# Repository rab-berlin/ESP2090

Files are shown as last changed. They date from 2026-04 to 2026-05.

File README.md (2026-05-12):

# Bring deinen Busch Microtronic 2090 ins 21. Jahrhundert!

ESP2090-Studio

Das ESP2090-Studio verbindet den klassischen Lerncomputer Busch Microtronic 2090 mit einem modernen ESP32. ESP2090 erweitert den Microtronic um flexible, programmierbare Peripherie.

Der Grundgedanke ist einfach: Der Microtronic bleibt das originale 4-Bit-System – das ESP2090-Studio sorgt dafür, dass er plötzlich Dinge kann, die er ursprünglich nie konnte, ohne ihn selbst zu ersetzen. Wir verbinden dafür die Ein- und Ausgänge des Microtronic mit einem [ESP32](https://de.wikipedia.org/wiki/ESP32), auf dem [MicroPython](https://micropython.org) läuft. So können benutzerdefinierte Python-Programme über festgelegte Funktionen und Protokolle mit dem Microtronic interagieren. 

Vom einfachen Blinklicht über anpassbaren Zufallszahlengenerator, 2095-Tape-Emulator, Tongenerator, beliebige Sensoren, Internet-Anbindung bis hin zu einem 8x8-Matrix-LED-"Bildschirm" für den Microtronic - über die Weboberfläche des ESP2090-Studios lässt sich alles konfigurieren und steuern. 

Webscreen

## Materialliste (BOM)

| Menge | Artikel | Preis (04/26) | Bemerkung |
| ---: | :--- | ---: | :--- |
| 1 | ESP32-C3 SuperMini | 1,70 | |
| 1 | SN74HCT244 8-fach Treiber | 2,60 | (10 St.) |
| 1 | CD4071 4-fach Oder-Gatter | 1,70 | (10 St.) |
| 2 | 4ch-2way-Levelshifter | 1,70 | (10 St., richtige Bauform beachten) |
| 1 | Buzzer, passiv | 1,50 | (10 St.) |
| 4 | Widerstand 470 Ohm | 2,00 | (Sortiment Widerstände 300 St.) |
| 4 | Widerstand 10k Ohm | - | (s.o.) |
| 1 | Widerstand 220 Ohm | - | (s.o.) |
| 1 | Widerstand 100 Ohm | - | (s.o.) |
| 2 | Kondensator 100 nF | 2,30 | (Sortiment Kondensatoren 300 St.) |
| 1 | Pfostenleiste 2,54 mm | 1,80 | (Sortiment male + female 20 St., benötigt male: 1 x 5, 1 x 3) |
| 1 | Buchsenleiste 2,54 mm | - | (s.o., benötigt female: 2 x 8 für ESP32) |
| 1 | IC-Sockel 14-polig | 2,20 | (Sortiment 66 St., für CD4071)
| 1 | IC-Sockel 20-polig | - | (s.o., für 74HCT244) |
| 18 | Metallösen 2,5 mm Innendurchmesser | 1,80 | (Sortiment 100 St., Stichwort: rivet, eyelet) |
| 1 | [Platine (PCB)](https://github.com/rab-berlin/ESP2090/tree/main/gerbers) | 9,00 | (5 St. aus Fernost - oder von mir, falls noch da) |
| 1 | WS2812B-LED-Matrix 8x8 | 1,80 | |
| 1 | Netzteil 5V 3A USB-C | 3,30 | |

Die Preise sind von AliExpress. Wer das alles frisch ordert, kommt ohne Platine für etwa 20 Euro weg - und hat danach noch viele Ersatzteile übrig. Ich bin aber sicher, dass du das meiste sowieso schon vorrätig hast. Lediglich den ESP, die Metallösen, die Platine und wahrscheinlich die LED-Matrix musst du wohl bestellen.

Du kannst natürlich auch ohne IC-Sockel und Buchsenleisten alles direkt auf die Platine löten. Ich persönlich hab´s aber lieber flexibel - versuch mal, einen falsch eingelöteten oder nicht funktionierenden IC wieder auszulöten...

Wer es richtig schön will, druckt sich noch einen passenden Busch-Bauteilträger dazu aus. ~~Daran arbeite ich noch...~~ [SCAD-](https://github.com/rab-berlin/ESP2090/blob/main/3d/ESP2090_mit_Zapfen.scad) und STL-Datei. Zur Befestigung der Platine am Träger brauchst du vier winzige Schrauben M2 und passende Muttern.

## Warum nur, warum?

Für den Test von neu geschriebenen oder geänderten Programmen habe ich zunächst den prima [Emulator von Michael Wessel](https://github.com/lambdamikel/Busch-2090) verwendet. Am PC entwickelt, auf SD-Karte geschrieben, in den Emulator umgestöpselt und übertragen... Haltnextnullnullrun...

Als ich dann auch mal auf dem "echten" Microtronic testen wollte, stieß ich - unter anderem - auf den Unterschied zwischen zufälligem und nicht so zufälligem Zufall. Also ergaben sich neue Notwendigkeiten:

- mehr auf dem originalen Busch Microtronic 2090 testen
- besondere Peripherie für meine Programme anschließen

Daher habe ich dann einen Raspberry Pi Zero W eingesetzt. Ein Python-Skript und ein paar Kabel mit Levelshifter übernahmen die Funktion des 2095-Kassetteninterfaces, und so konnte ich meine Ideen relativ schnell und unkompliziert über WLAN auf den Pi und von dort auf den Original-2090 bringen.

Für einige dieser neuen Programme wiederum benötigte ich manchmal auch Peripherie am Microtronic, die ich nicht immer mit Busch-Baukästen umsetzen konnte (oder wollte). Das erledigte zuerst ein Arduino Nano mit entsprechendem C-Programm, anschließend übernahm der Pi auch diese Aufgabe.

Der Raspberry Pi (also auch der von mir verwendete Zero) ist im Prinzip ein vollwertiger Computer mit Linux-Betriebssystem. Damit konnte ich natürlich alle Peripherie-Aufgaben bequem erledigen, und der Pi wäre auch eine bestens geeignete Hardware-Grundlage für alle weiteren Vorhaben gewesen. Irgendwie störte mich aber der Gedanke, dass zwischen dem Microtronic und dem Pi ein so großes _intellektuelles Gefälle_ herrschte. Ich wollte stattdessen, dass sich zwei Microcontroller "auf Augenhöhe" miteinander unterhalten - wenn auch mit 45 Jahren Altersunterschied. 

Was mich außerdem störte, ist die Preisentwicklung bei der Raspberry Pi Foundation. Es fing mal an als Experimentiercomputer zu einem Preis, den sich jeder lernwillige Einsteiger leisten konnte. Inzwischen werden teilweise Preise von 200 Euro für einen ausgebauten Pi aufgerufen. Obwohl es sicher gute Gründe dafür geben mag, ist das (für mich) nicht mehr unterstützenswert.

Die Leitidee sollte sein: Mit so wenig wie möglich so viel wie möglich erreichen. 

Meine Wahl fiel dann auf den ESP32 - nicht zuletzt, weil ich den Vorgänger ESP8266 in der Arduino-Umgebung schon öfter benutzt hatte. Der erste Gedanke war dann auch, dem ESP alles, was er wissen muss, in C beizubringen, um als idealer peripherer Begleiter für den Microtronic zu dienen. Einige gedankliche Iterationen später war die Frage dann aber: Wäre es nicht noch schöner, wenn man zur Laufzeit neue Ideen testen könnte, ohne die Firmware über die Arduino-IDE jeweils neu programmieren und flashen zu müssen? Wenn man also beliebige User-Skripte zur Laufzeit direkt aufrufen und ausführen könnte? 

C und Arduino-IDE fielen damit raus. Python rückte ins Zentrum, weil es zur Laufzeit interpretiert wird, und der Microtronic sowieso kein Geschwindigkeitsmonster ist. Genauer gesagt, die Wahl fiel auf MicroPython - womit die Ideen letztlich alle umsetzbar schienen. Und außerdem wollte ich mal wieder was neues lernen.

Entsprechend der Leitidee _Reduce to the max_ sollte es dann der ESP32-C3-Supermini sein, da dieser nur ca. 2 Euro kostet und genug GPIOs bietet für alle Ein- und Ausgänge des Microtronic sowie für ein bisschen zusätzliche Funktionen. 

## Schaltung

Die [Schaltung des ESP2090-Studios](https://github.com/rab-berlin/ESP2090/blob/main/documents/ESP2090.pdf) ist verhältnismäßig einfach. 

Der ESP32 arbeitet mit 3,3 Volt Betriebsspannung, der Microtronic hingegen mit 5 Volt (genauer gesagt: sogar 5,7 Volt - nachmessen!). Daher sind in den Signalwegen jeweils Levelshifter eingebaut. Da wir es mit verhältnismäßig langsamen Signalen im Bereich von Millisekunden zu tun haben, muss man über die Schaltgeschwindigkeit der Levelshifter nicht besonders intensiv nachdenken. Billige Teile aus China funktionieren gut.

Ich habe darauf geachtet, dass die Ein- und Ausgänge des Microtronic elektrisch vom ESP entkoppelt sind, das heißt, sie sollten auch bei gleichzeitigem Anschluss des ESP2090-Studios nach wie vor nutzbar bleiben, falls z.B. weitere Peripherie aus dem Busch-Sortiment verwendet wird. Für diese Entkopplung werden zwei ICs eingesetzt, ein CD4071 und ein 74HCT244.

### Eingänge

Jeder Eingang des Microtronic ist an je einen Ausgang eines ODER-Gatters (CD4071) angeschlossen. Je ein Eingang eines ODER-Gatters ist mit einem GPIO des ESP32 verbunden, der andere Eingang des Gatters ist "frei" (kann also wie bisher als Eingang des 2090 genutzt werden). So können weiterhin beliebige Peripherie-Schaltungen an den Microtronic angeschlossen werden - ohne dass es zu elektrischer Beeinflussung durch den ESP32 kommt. 

Die Eingänge des 4071 sind extrem hochohmig, über Ströme muss man sich also keine Gedanken machen.

### Ausgänge 

Jeder Ausgang des Microtronic ist an je zwei Eingänge eines 74HCT244 angeschlossen. Dadurch wird ein Microtronic-Ausgang praktisch "verdoppelt" - eine Ausgangskopie bleibt unabhängig nutzbar, daran kann also wie bisher beliebige (Busch-)Peripherie angeschlossen werden. Die andere Ausgangskopie ist mit einem GPIO des ESP verbunden. Dadurch kann das ESP2090-Studio alle Veränderungen an den Ausgängen des Microtronic überwachen, ohne eventuell angeschlossene andere Peripherie elektrisch zu stören. 

Es ist zu beachten, dass der 74HCT244 maximal 20 mA an seinen Ausgängen liefert. Mehr sollte man auch dem Microtronic niemals abverlangt haben, wenn man seine Ausgänge nicht überlasten wollte - laut Anleitungsbuch 2. Teil, S. 41: "maximal 15 mA". Wer mehr will oder braucht, steuert mit dem Ausgang wie üblich erstmal einen Transistor an.

## Was kann ich damit machen?

Die einfache Antwort: alles. 

Prinzipiell brauchst du nur ein passendes Python-Script auf dem ESP2090, welches auf die Signale an den vier Ausgängen des Microtronic passend reagiert und - falls nötig - die richtigen Signale zur gewünschten Zeit an die Eingänge des Microtronic sendet. 

Die ernüchternde Antwort: natürlich nicht alles, weil der Programmspeicher des Microtronic eben doch nur 256 Befehle umfasst. Und die Anzahl der Register mit 16 (plus 16 Speicherregister) auch recht begrenzt ist.

Der Spaß liegt wie immer darin, mit diesen Einschränkungen eben doch etwas zu schaffen, das "sinnvoll" und funktional ist.

### Protokolle 

Wenn du bisher noch nie etwas mit Protokollen zu tun haben wolltest (hast du aber, weil du gerade im Internet unterwegs bist) - jetzt solltest du damit anfangen, wenn du dem Microtronic die _Welt der Dinge_ zugänglich machen willst.

Als einfaches Beispiel für ein Protokoll dient der "Bildschirm". Um alle 8x8 Pixel der LED-Matrix anzusteuern, werden die Speicherregister 0-F des Microtronic nacheinander auf die Ausgänge gelegt - also 16 Nibbles, insgesamt 64 Bit. Damit dies zu genau festgelegten Zeiten passiert, sendet das ESP2090-Studio zuerst einen Request (REQ), wartet auf eine Bestätigung (ACK) und liest dann alle 9 Millisekunden die Ausgänge - denn bei deaktivierter Anzeige benötigt der 2090 ziemlich genau 9 ms für die Ausführung einer Instruktion.

Auf diese Weise können auch andere Protokolle zum Datenaustausch zwischen Microtronic und ESP32 realisiert werden. 

## Beispiele

### Microtronic goes Hollywood

...

### [BerlinUhr2090](https://github.com/rab-berlin/BerlinUhr2090)

### [Life2090](https://github.com/rab-berlin/Life2090)

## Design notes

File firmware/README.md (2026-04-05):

Die _"Firmware"_ für das ESP2090-Studio besteht aus:
- MicroPython, installiert auf dem ESP32-C3
- einigen Python-Skripten, im einzelnen
  - main.py für die eigentliche Funktionalität des ESP2090-Studios
  - boot.py für GPIO-Initialisierung und Verbindung mit WLAN
  - basicweb.py für einen eigenen AP, falls keine WLAN-Verbindung möglich ist
  - microdot.py als Bibliothek für den schlanken und effizienten Microdot-Webserver
- einer HTML-Webseite index.html

Später werden noch folgende Dateien erzeugt:
- wifi.json für die WLAN-Credentials
- webrepl_cfg.py für die REPL-Credentials, falls z.B. Thonny verwendet wird

Außerdem gibt es noch zwei Ordner auf dem ESP32:
- logs für die Logdateien
- userscripts für die Python-Skripte, die zur Laufzeit geladen und gestartet werden

In User-Skripten kann auf folgende Objekte und Funktionen des ESP2090-Studios zugegriffen werden:

- Ausgänge des ESP (**out_1** bis **out_4**) - damit werden die Eingänge des Microtronic angesteuert
- Eingänge des ESP (**in_1** bis **in_4**) - damit werden die Ausgänge des Microtronic gelesen
- Objekte **tasteG** und **tasteH** - die entsprechenden Buttons auf der Weboberfläche
- Funktion **setOutputs** - setzt out_1 bis out_4 auf den binären Wert des Aufruf-Parameters
- Funktion **log** - schreibt ins Log
- Funktion **beep** - erzeugt Ton mit übergebener Frequenz
- Funktion **setColors** - legt mit einer Matrix die Anzeigefarben der LEDs fest
- Das gesamte Neopixel-Objekt **np** für komplexere Anforderungen an die LED-Matrix

Das alles kann natürlich selbst in der main.py geändert werden. Ich selbst ändere es praktisch andauernd... also keine Garantie, dass dieser Text den jeweils aktuellsten Stand wiedergibt.

Damit die anderen Tasks, insbesondere der Webserver, nicht "sterben", sollten User-Skripte 
- kurz sein und praktisch gleich wieder enden oder
- den asyncio-Regeln für kooperatives Multitasking folgen:
  - Aufruf-Syntax mit _async def ..._ statt _def ..._
  - innerhalb der Funktion warten mit _await_ statt _sleep_, um die Kontrolle an andere Tasks zu übergeben

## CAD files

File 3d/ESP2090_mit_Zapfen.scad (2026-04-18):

// --- PARAMETER ---
width = 116;          
depth = 76;           
height = 8;           
outer_radius = 1;     
wall_thickness = 2.0; 

// Boden-Öffnungen
bottom_opening_w = 88;
bottom_opening_d = 68;
inner_step_w = 90.5;
inner_step_d = 70.5;
step_height = 2;      

// Zapfen (Pins)
pin_dia = 3.1;
pin_dist_w = 100; 
pin_dist_d = 60;  
pin_extra_height = 3.2; 
pin_total_h = height + pin_extra_height;

// Stabilitäts-Konus (unten)
conus_base_dia = 8.0;  
conus_height = 5.0;    

// Verjüngung Spitze (oben)
tip_taper_h = 1.5;     
tip_taper_dia = 2.0;   

// Befestigungslaschen (Viertelkreise)
tab_radius = 4.5;
tab_height = 2;
hole_dia = 2.00; 

// ZIEL-ABSTÄNDE DER LÖCHER (Mittelpunkt zu Mittelpunkt)
target_dist_x = 86;
target_dist_y = 66;

$fn = 64;             

// Hilfsmodul für die abgerundete Grundform
module rounded_box(w, d, h, r) {
    hull() {
        translate([r, r, 0]) cylinder(h=h, r=r);
        translate([w - r, r, 0]) cylinder(h=h, r=r);
        translate([r, d - r, 0]) cylinder(h=h, r=r);
        translate([w - r, d - r, 0]) cylinder(h=h, r=r);
    }
}

// --- MODELLIERUNG ---
difference() {
    union() {
        // 1. DIE SCHALE
        difference() {
            rounded_box(width, depth, height, outer_radius);
            
            translate([wall_thickness, wall_thickness, wall_thickness])
                rounded_box(width - 2*wall_thickness, 
                            depth - 2*wall_thickness, 
                            height, 
                            max(0.1, outer_radius - wall_thickness));

            translate([(width - bottom_opening_w)/2, (depth - bottom_opening_d)/2, -0.1])
                cube([bottom_opening_w, bottom_opening_d, wall_thickness + 0.2]);
                
            translate([(width - inner_step_w)/2, (depth - inner_step_d)/2, step_height])
                cube([inner_step_w, inner_step_d, height]);
        }

        // 2. DIE VIER ZAPFEN
        start_x_pins = (width - pin_dist_w) / 2;
        start_y_pins = (depth - pin_dist_d) / 2;

        for (x = [0, pin_dist_w]) {
            for (y = [0, pin_dist_d]) {
                translate([start_x_pins + x, start_y_pins + y, 0]) {
                    cylinder(h = pin_total_h - tip_taper_h, d = pin_dia);
                    translate([0, 0, pin_total_h - tip_taper_h])
                        cylinder(h = tip_taper_h, d1 = pin_dia, d2 = tip_taper_dia);
                    translate([0, 0, wall_thickness])
                        cylinder(h = conus_height, d1 = conus_base_dia, d2 = pin_dia);
                }
            }
        }

        // 3. DIE LASCHEN (Viertelkreise)
        edge_x = (width - bottom_opening_w) / 2;
        edge_y = (depth - bottom_opening_d) / 2;

        for (tx = [0, bottom_opening_w]) {
            for (ty = [0, bottom_opening_d]) {
                angle = (tx == 0 && ty == 0) ? 0 : 
                        (tx > 0 && ty == 0) ? 90 : 
                        (tx > 0 && ty > 0) ? 180 : 270;
                translate([edge_x + tx, edge_y + ty, 0])
                    rotate([0, 0, angle])
                    intersection() {
                        cylinder(h = tab_height, r = tab_radius);
                        cube([tab_radius, tab_radius, tab_height]);
                    }
            }
        }
    }

    // 4. ABZUG DER LÖCHER (Exakt 86x66mm)
    // Wir platzieren die Löcher relativ zum Bauteilmittelpunkt
    center_x = width / 2;
    center_y = depth / 2;

    for (lx = [-target_dist_x/2, target_dist_x/2]) {
        for (ly = [-target_dist_y/2, target_dist_y/2]) {
            translate([center_x + lx, center_y + ly, -1]) 
                cylinder(h = tab_height + 2, d = hole_dia);
        }
    }
}

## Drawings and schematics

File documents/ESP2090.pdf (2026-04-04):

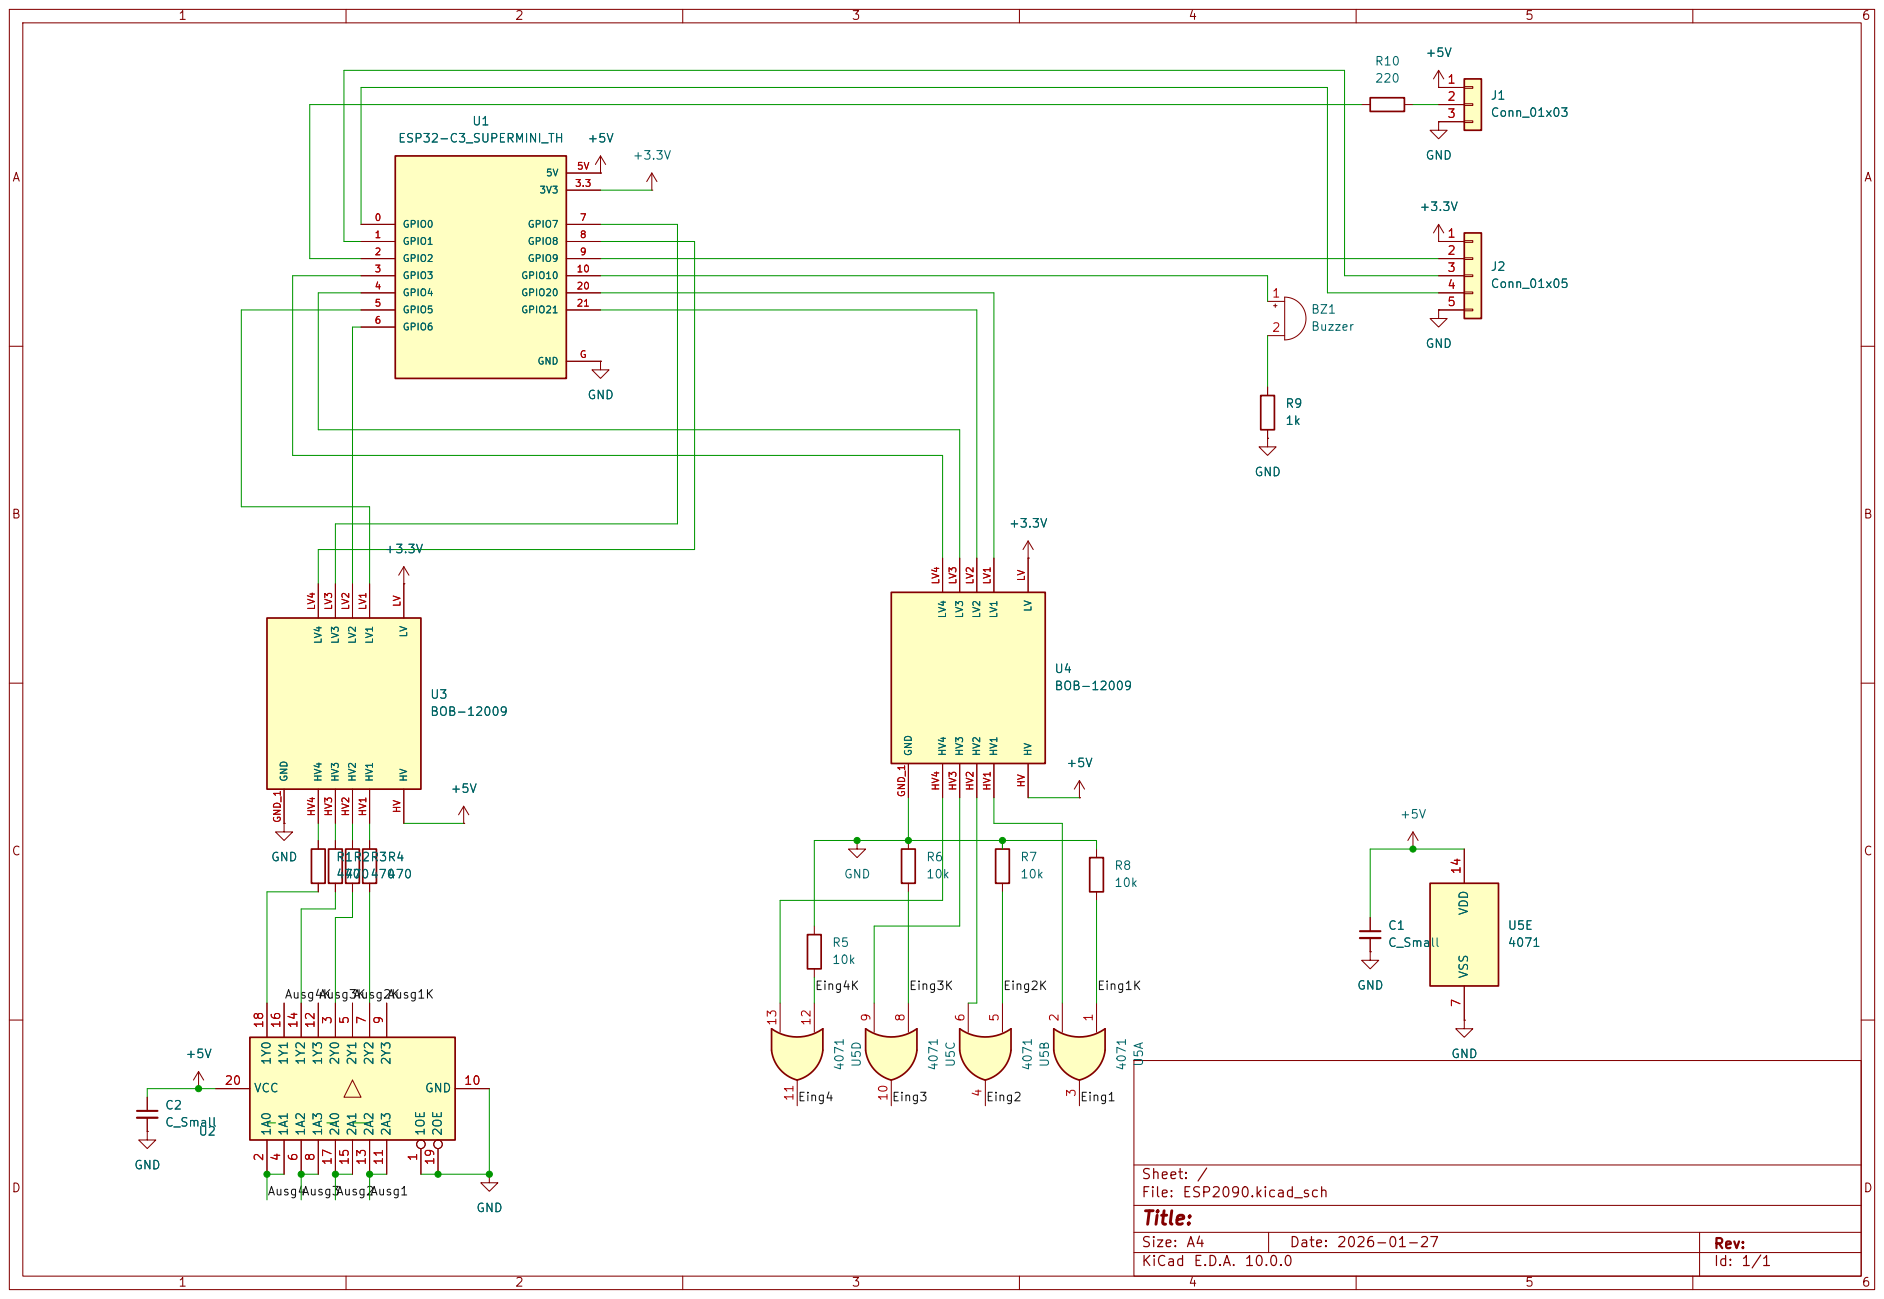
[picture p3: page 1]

3 U5A 4071 +5V GND GND_1 HV HV HV1 HV1 HV2 HV2 HV3 HV3 HV4 HV4 LV LV LV1 LV1 LV2 LV2 LV3 LV3 LV4 LV4 U4BOB-12009R8

Size: A4 | Rev:

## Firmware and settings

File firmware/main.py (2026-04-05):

import uasyncio as asyncio
from microdot import Microdot
from machine import Pin, PWM
import machine, network, gc, time, os
import neopixel
import sys

# ================= GPIO =================
# out_1 - out_4, in_1 - in_4 in boot.py 

OUTPUTS = [out_1, out_2, out_3, out_4]
INPUTS = [in_1, in_2, in_3, in_4]

# ----- Web-Taster -----
tasteG = {"pressed": False}
tasteH = {"pressed": False}

def setOutputs(value):
    out_1.value(value & 1)
    value >>= 1
    out_2.value(value & 1)
    value >>= 1
    out_3.value(value & 1)
    value >>= 1
    out_4.value(value & 1)
    
def getInputsList():
    return [pin.value() for pin in INPUTS]

def getInputsNumber():
    # noch dummy
    return 0

# ================= LED MATRIX =================

matrix_tasks_running = False
matrix_display_task_handle = None
matrix_task_handle = None

LED_PIN = 2
ROWS = 8
COLS = 8
NUM_LEDS = ROWS * COLS

WAIT_AFTER_REQ = 30000
WAIT_AFTER_ACK = 13500
NIBBLE_INTERVAL = 9217
NUM_NIBBLES = 16
POST_DISPLAY_WAIT = 30000

COLORS = {
    "rot":     (10,0,0),
    "orange":  (10,4,0),
    "gelb":    (10,10,0),
    "gruen":   (0,8,0),
    "tuerkis": (0,8,6),
    "blau":    (0,0,10),
    "violett": (6,0,10),
    "magenta": (10,0,6),
    "weiss":   (10,10,10),
    "schwarz": (0,0,0),
}
COLOR_OFF = (0,0,0)

np = neopixel.NeoPixel(Pin(LED_PIN), NUM_LEDS)

matrix_dirty = True # initial
matrix = bytearray(NUM_LEDS)
color_matrix = [[None]*COLS for _ in range(ROWS)]


def phys_index(row, col):
    """
    Liefert den physischen NeoPixel-Index für ein Pixel an
    logischer Position (row, col) in einer 8x8-Matrix.
    
    Annahme physische Verdrahtung:
    Pixel 0 = unten links
    Pixel 1 = direkt darueber
    Pixel 8 = rechts neben Pixel 0
    """
    return col * ROWS + row


def start_matrix_tasks():
    global matrix_display_task_handle, matrix_task_handle, matrix_tasks_running

    if matrix_tasks_running:
        log("LED task already running")
        return

    matrix_display_task_handle = asyncio.create_task(matrix_display_task())
    matrix_task_handle = asyncio.create_task(matrix_task())

    matrix_tasks_running = True
    log("LED task started")


def stop_matrix_tasks():
    global matrix_display_task_handle, matrix_task_handle, matrix_tasks_running

    if not matrix_tasks_running:
        log("Matrix already stopped")
        return

    if matrix_display_task_handle:
        matrix_display_task_handle.cancel()
        matrix_display_task_handle = None

    if matrix_task_handle:
        matrix_task_handle.cancel()
        matrix_task_handle = None

    matrix_tasks_running = False
    log("LED task stopped")


def clearPixel(pos):
    matrix[pos] = 0
    matrix_dirty = True

def setPixel(pos):
    matrix[pos] = 1
    print(matrix)
    matrix_dirty = True


def setColors(new_matrix):
    """
    Setzt die komplette 8x8 color_matrix auf new_matrix.
    new_matrix muss 8x8 sein.
    """
    global color_matrix
    if len(new_matrix) != ROWS or any(len(row) != COLS for row in new_matrix):
        log("Fehler: Color-Matrix muss 8x8 sein")
        return
    color_matrix = new_matrix[::-1]


async def matrix_display_task():
    global matrix_dirty

    while True:

        if matrix_dirty:

            for r in range(ROWS):
                for c in range(COLS):

                    index = phys_index(r, c)

                    if matrix[r*COLS + c]:  # Zugriff auf 1D-Array
                        cname = color_matrix[r][c]
                        color = COLORS.get(cname, COLORS["rot"])
                        np[index] = color
                    else:
                        np[index] = COLOR_OFF

            np.write()
            matrix_dirty = False
            matrix_print_console(matrix)

        await asyncio.sleep_ms(50)


def matrix_print_console(matrix):
    sys.stdout.write("\x1b[2J")
    sys.stdout.write("\x1b[H")

    for r in reversed(range(ROWS)):  # Zeilen von oben nach unten
        line = ""
        for c in range(COLS):
            idx = r * COLS + c
            line += "*" if matrix[idx] else " "
            line += " "
        print(line)
    print()
    

async def matrix_task():
    global matrix_dirty

    while True:
                
        # =========================
        # 1. REQ setzen
        # =========================
        out_1.value(1)  # REQ = HIGH
        req_time = time.ticks_us()
        ack_time = None

        # =========================
        # 2. Auf ACK warten (max 18 ms)
        # =========================
        while True:
                        
            now = time.ticks_us()
            elapsed = time.ticks_diff(now, req_time)

            # ACK = 0001
            if in_1.value():
                ack_time = time.ticks_us()
                out_1.value(0)  # REQ sofort LOW
                #print(time.ticks_diff(ack_time, req_time))
                break

            # Timeout
            if elapsed >= WAIT_AFTER_REQ:
                out_1.value(0)
                # kein ACK einfach neuer Versuch
                break

        if ack_time is None:
            # Retry (kleine Pause damit CPU nicht stirbt)
            #await asyncio.sleep_ms(0)
            continue # zum Schleifenanfang

        # =========================
        # 3. MSB_WAIT_TIME warten blocking
        # =========================
        start_time = time.ticks_add(ack_time, WAIT_AFTER_ACK)
        while time.ticks_diff(start_time, time.ticks_us()) > 0:
            pass

        # =========================
        # 4. Daten einlesen
        # =========================
        next_time = time.ticks_add(start_time, NIBBLE_INTERVAL)
        idx = 0
        
        for _ in range(NUM_NIBBLES):
            while time.ticks_diff(next_time, time.ticks_us()) > 0:
                pass
            matrix[idx] = in_1.value(); idx += 1
            matrix[idx] = in_2.value(); idx += 1
            matrix[idx] = in_3.value(); idx += 1
            matrix[idx] = in_4.value(); idx += 1
            next_time = time.ticks_add(next_time, NIBBLE_INTERVAL)
            
        matrix_dirty = True

        # =========================
        # 5. Mini-Yield für asyncio
        # =========================
        await asyncio.sleep_ms(20)



# ================= SERVER =================
app = Microdot()
current_task = None
LOG_SIZE = 40
log_buffer = []

# ================= FILE LOGGING =================
LOG_DIR = "logs"
file_log_buffer = []

def ensure_log_dir():
    try:
        os.mkdir(LOG_DIR)
    except:
        pass

def current_log_filename():
    t = time.localtime()
    return "{}/log_{:04d}-{:02d}-{:02d}.txt".format(LOG_DIR, t[0], t[1], t[2])

def log(msg):
    msg = str(msg)[:100]
    log_buffer.append(msg)
    file_log_buffer.append(msg)
    if len(log_buffer) > LOG_SIZE:
        log_buffer.pop(0)

def flush_now():
    if file_log_buffer:
        try:
            ensure_log_dir()
            fname = current_log_filename()
            with open(fname, "a") as f:
                for line in file_log_buffer:
                    f.write(line + "\n")
            file_log_buffer.clear()
        except Exception as e:
            log("Log error "+str(e))

async def flush_task():
    while True:
        await asyncio.sleep(5)
        flush_now()

# ================= USER SCRIPT =================

def indent(txt,n):
    return "\n".join(" "*n + line for line in txt.split("\n"))

async def run_user_script(code):
    global current_task

    try:

        wrapped=f"""
import uasyncio as asyncio
async def __user_task():
{indent(code,4)}
"""

        ns={
            "out_1":out_1,"out_2":out_2,"out_3":out_3,"out_4":out_4,
            "in_1":in_1,"in_2":in_2,"in_3":in_3,"in_4":in_4,
            "tasteG":tasteG,
            "tasteH":tasteH,
            "setOutputs":setOutputs,
            "log":log,
            "beep":beep,
            "setColors":setColors,
            "np":np
        }

        exec(wrapped,ns)

        current_task=asyncio.create_task(ns["__user_task"]())
        log("User script started")

        await current_task

    except asyncio.CancelledError:
        log("User script stopped")

    except Exception as e:
        log("ERROR "+str(e))

    gc.collect()

# ================= BUSCH UPLOAD =================

delay_bit_us = 10000
delay_after_value_us = 10000

def clock_signal(pin, delay_us):
    pin.value(1)
    time.sleep_us(delay_us // 2)
    pin.value(0)
    time.sleep_us(delay_us // 2)

def load_instruction_to_busch2090(instr):

    for y in range(3):

        mask = 1

        for z in range(4):

            out_1.value(1 if (int(instr[y], 16) & mask) else 0)

            if y == 0 and z == 0:
                out_3.value(1)
                time.sleep_us(delay_bit_us)
            else:
                clock_signal(out_2, delay_bit_us)

            mask <<= 1

    setOutputs(0)
    time.sleep_us(delay_after_value_us)

def is_valid(instr):
    return len(instr) == 3 and all(c in "0123456789ABCDEF" for c in instr)

def send_busch_file(filename):

    log("Busch upload started")

    try:
        with open(filename) as f:
            for line in f:

                line=line.strip().upper()

                if len(line)<3:
                    continue

                instr=(line[0:3]
                    .replace("I","1")
                    .replace("L","1")
                    .replace("O","0")
                    .replace("Q","0"))

                if is_valid(instr):
                    load_instruction_to_busch2090(instr)

    except:
        log("Upload file missing")

    setOutputs(0)
    log("Busch upload finished")

@app.post('/busch_upload')
async def busch_upload(req):

    filename="busch_upload.mic"

    body=req.body
    sep=b"\r\n\r\n"

    start=body.find(sep)+len(sep)
    data=body[start:]

    end=data.rfind(b"\r\n------")

    if end>0:
        data=data[:end]

    with open(filename,"wb") as f:
        f.write(data)

    send_busch_file(filename)

    return "Busch transfer done"

# ================= BUZZER =================

BUZZER_PIN = 10
buzzer_pwm = PWM(Pin(BUZZER_PIN))
buzzer_pwm.duty_u16(0)

beep_queue = []

def beep(freq,duration_ms):
    beep_queue.append((freq,duration_ms))

async def buzzer_play_task():
    while True:
        if beep_queue:
            freq,dur=beep_queue.pop(0)
            if freq>0:
                buzzer_pwm.freq(freq)
                buzzer_pwm.duty_u16(20000)
            else:
                buzzer_pwm.duty_u16(0)
            await asyncio.sleep_ms(dur)
            buzzer_pwm.duty_u16(0)
        else:
            await asyncio.sleep_ms(10)

# ================= ROUTES =================

@app.get('/')
async def index(req):
    with open("index.html") as f:
        return f.read(),200,{'Content-Type':'text/html'}

@app.get('/logs')
async def logs(req):
    return "\n".join(log_buffer),200,{'Content-Type':'text/plain'}

@app.post('/save')
async def save(req):

    name=req.args.get("name","script.py")

    body=req.body.decode() if isinstance(req.body,bytes) else req.body

    with open(name,"w") as f:
        f.write(body)

    return "Saved "+name

@app.get('/load')
async def load(req):

    name=req.args.get("name","script.py")

    try:
        with open(name) as f:
            return f.read(),200,{'Content-Type':'text/plain'}
    except:
        return "File not found"

@app.get('/run')
async def run(req):

    global current_task

    if current_task and not current_task.done():
        return "Script already running"

    name=req.args.get("name","script.py")

    try:
        with open(name) as f:
            code=f.read()
    except:
        return "File not found"

    asyncio.create_task(run_user_script(code))

    return "Started "+name

@app.get('/stop')
async def stop(req):

    global current_task

    if current_task:
        current_task.cancel()
        current_task=None
        setOutputs(0)
        flush_now()
        return "Stopped"

    return "No script"


# ================= LIST PY FILES =================
@app.get("/list_py")
async def list_py(req):
    files = []
    try:
        for f in os.listdir("userscripts"):
            if f.endswith(".py"):
                files.append(f)
    except Exception as e:
        log("Error listing userscripts: "+str(e))
    return files

# ================= WEB TASTER =================
async def reset_taste_after(taste_var, delay_ms=500):
    await asyncio.sleep_ms(delay_ms)
    taste_var["pressed"] = False

@app.get('/set_taste')
async def set_taste(req):
    global current_task
    if not current_task or current_task.done():
        return "No active user script"

    ttype = req.args.get("type","G")
    try:
        val = int(req.args.get("value","0"))
    except:
        val = 0

    taste_var = tasteH if ttype=="H" else tasteG

    if val==1:
        taste_var["pressed"] = True
        log(f"Taste {ttype} pressed")
        asyncio.create_task(reset_taste_after(taste_var,500))

    return "OK"

@app.get("/reset")
async def reset(req):
    log("ESP restart triggered")
    await asyncio.sleep_ms(100)
    machine.reset()
    return "Restarting..."


@app.get("/matrix_control")
async def matrix_control(req):
    action = req.args.get("action","")

    if action == "start":
        start_matrix_tasks()
        return "Matrix started"

    if action == "stop":
        stop_matrix_tasks()
        return "Matrix stopped"

    return "Invalid action"

# ================= CHECK SCRIPT RUNNING =================
@app.get("/is_script_running")
async def is_script_running(req):
    return "1" if current_task and not current_task.done() else "0"


# ================= MAIN =================
async def main_task():

    asyncio.create_task(flush_task())
    asyncio.create_task(buzzer_play_task())
    #asyncio.create_task(matrix_display_task())
    #asyncio.create_task(matrix_task())

    log("Server started")

    await app.start_server(port=8080)

asyncio.run(main_task())

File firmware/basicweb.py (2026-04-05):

import socket
import json
import network

CONFIG_FILE = "wifi.json"

def save_config(ssid, password):
    with open(CONFIG_FILE, "w") as f:
        json.dump({"ssid": ssid, "password": password}, f)

def scan_networks():
    sta = network.WLAN(network.STA_IF)
    sta.active(True)

    nets = sta.scan()
    ssids = []

    for net in nets:
        ssid = net[0].decode()
        if ssid not in ssids:
            ssids.append(ssid)

    return ssids

def web_page(ssids):
    options = ""
    for s in ssids:
        options += '<option value="{}">{}</option>'.format(s, s)

    return """\
HTTP/1.1 200 OK

<html>
    <h2>WiFi Setup</h2>
    <form method="post">
        SSID:
        <select name="ssid">
            {}
        </select><br><br>

        oder manuell:
        <input name="ssid"><br><br>

        Passwort:
        <input name="password" type="password"><br><br>

        <input type="submit">
    </form>
</html>
""".format(options)

def parse_post(data):
    try:
        body = data.split("\r\n\r\n")[1]
        params = {}

        for pair in body.split("&"):
            k, v = pair.split("=")
            params[k] = v.replace("%20", " ")

        return params
    except:
        return {}

def start():
    ssids = scan_networks()
    print("Gefundene Netzwerke:", ssids)

    addr = socket.getaddrinfo("0.0.0.0", 80)[0][-1]
    s = socket.socket()
    s.bind(addr)
    s.listen(1)

    print("Config-Webserver: http://192.168.4.1")

    while True:
        cl, addr = s.accept()
        request = cl.recv(1024).decode()

        if "POST" in request:
            params = parse_post(request)

            ssid = params.get("ssid", "")
            password = params.get("password", "")

            if ssid:
                save_config(ssid, password)

                cl.send("HTTP/1.1 200 OK\r\n\r\nGespeichert! Neustart...")
                cl.close()

                import machine
                machine.reset()
                return

        cl.send(web_page(ssids))
        cl.close()

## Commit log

2026-04-03 Expand README with ESP32 integration details
    Added details about integrating ESP32 with the Microtronic 2090.
2026-04-03 Change prototype image in README
    Updated prototype image in README.md.
2026-04-05 Revise Frame subroutine code for LED matrix control
    Updated the Frame subroutine code in the README to reflect changes in handling REQ and ACK signals for the LED matrix.
2026-04-18 Revise README with component details and usage notes
    Updated component list and added notes on flexibility and mounting.
2026-04-18 Revise BOM prices and notes in README
    Updated prices and remarks in the BOM for various components.
2026-04-18 Update BOM table header formatting in README
2026-04-18 Add links to SCAD and STL files in README
    Updated README with links to SCAD and STL files for the Busch-Bauteilträger.
2026-11-09 ANLEITUNG/README: Klonen per esptool und Hinweise auf alten logs-Ordner entfernt
    Claude-Session: https://claude.ai/code/session_01U7fekmJg6yFkdWhWqNYD27
2026-11-09 Doku: Userscripts und LED-Matrix ausgelagert, Beispiele Ton, Web-Taster, Zufallszahl, demo_matrix, film_color
    - README: Abschnitt Protokolle neu (zwei Wege, Links)
    - docs/Userscripts.md: Richtung der Signale, Protokollmuster, Regeln, 4 Beispiele
    - docs/LED-Matrix.md: Ablauf, Block- und Zeichenmodus, Senderoutinen, Palette, Umstellung
    - docs/bilder: Zeitablauf und Koordinaten (SVG)
    - program/ton, webtaster, zufallszahl: .src, .mic, .py
    - program/demo_matrix, film_color: .src, .mic (aus der Entwicklung)
    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
2026-11-09 LED-Matrix-Doku: Bit- und Farbmatrix erklaert, Register statt Nibble im Blockmodus, Bilder je Abschnitt, Versionshinweise und .src entfernt
    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
2026-11-09 LED-Matrix-Doku: Bild und Erklaerung zur 0,7-ms-Kontrolle (2090 schaltet Ausgaenge nacheinander)
    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
2026-11-09 Doku: 166 us ab der ersten erkannten Aenderung praezisiert
    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
2026-11-09 BerlinUhr und film_color aus program/ entfernt (eigene Repos), Links angepasst, Film2090 im README
    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
2026-11-09 Matrix: ACK 13 sichert und holt Farb- und Bitmatrix zurueck
    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
2026-11-09 ACK 15 als Schlafmodus: Firmware, Doku und demo_matrix
    - firmware/: main.py, matrix_draw.py, index.html auf den Stand von
    esp2090-firmware (PR #28): nach ACK 15 kein REQ, bis F an den Ausgaengen weckt;
    Anzeige an/aus entfaellt.
    - docs/LED-Matrix.md: ACK 15 = Schlafmodus, Abschnitt Schlafmodus mit Routine
    fuer Schlafen und Wecken (wie in Microtris2090, Snake2090, Springer2090).
    - demo_matrix: Vorfuehrung 9 schlaeft bis zur Taste (208 Befehle).
    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
2026-11-10 LED-Matrix.md: nach dem Wecken auf REQ warten
    Claude-Session: https://claude.ai/code/session_01U7feknfJ7V1oMvYJb4EUZc
2026-11-10 Schlafen und Wecken: gehaltenes F, ein Befehl je Wecken; Firmware und demo_matrix nachgezogen
    - firmware/: main.py, index.html auf dem Stand von esp2090-firmware (PR #39):
    Wecken mit gehaltenem F, ACK direkt aus dem F = ein Befehl und wieder schlafen,
    F > 40 ms weckt immer, Bilder sofort anzeigen, Konsolenausgabe aus.
    - docs/LED-Matrix.md: Abschnitt Schlafen und Wecken neu.
    - demo_matrix: Vorfuehrung 9 weckt mit gehaltenem F (212 Befehle).
    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
2026-11-11 README: Zoll-Nachtrag, Einschaltreihenfolge, Userscripts und LED-Matrix eingebunden
    - Nachtrag zur Kostenschätzung: 3 Euro Zoll je Warengruppe auf China-Lieferungen
    - Hinweis bei den Ausgängen: stromloser ESP, ca. 4 mA je Ausgang, zuerst ESP einschalten
    - docs/Userscripts.md und docs/LED-Matrix.md direkt in die README übernommen
    (Links und Bildpfade angepasst, Überschriften eindeutig), Einzeldateien entfernt
    - Link in firmware/README.md auf den neuen Abschnitt umgestellt
    Claude-Session: https://claude.ai/code/session_01U7fekotKy5A1DouPHo1eyh
2026-11-11 README: Inhaltsverzeichnis, Stromversorgung, Schnellstart, Lizenz, weitere Projekte
    - Inhaltsverzeichnis nach dem Einleitungsbild
    - Abschnitt Stromversorgung (USB-C, Strombudget, LED_MAX_MA, Einschaltreihenfolge)
    - Schnellstart: Kurzfassung von firmware/ANLEITUNG.txt
    - Projekte: Microtris2090, Snake2090, Springer2090 ergänzt
    - Lizenz: CC0 1.0 Universal (LICENSE-Datei + Abschnitt)
    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
2026-11-11 README: Abschnitt Protokolle entfernt, Einleitung in 'Protokolle: Nibbles und Zeit' übernommen
    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
2026-11-11 README: Reihenfolge beim Starten der Userscript-Beispiele (erst Upload, dann starten)
    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
2026-11-14 README: Abschnitt "Die Firmware: wie das ESP2090 innen tickt" mit Schichtengrafik
    asyncio statt Threads, Userscripts als Task, warum Microdot, Matrix und Upload
    als zeitkritische Ausnahmen, WLAN-Einrichtung, LED-Strombegrenzung.
    Neue Grafik docs/bilder/firmware-schichten.svg.
    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
